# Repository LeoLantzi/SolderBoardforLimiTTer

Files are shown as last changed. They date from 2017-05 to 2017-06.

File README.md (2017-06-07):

# SolderBoardforLimiTTer
Ideas to solder LimiTTer componets on a pcb board instead of wiring, to make it simpler and save space.

worked for me, but put the charger bit outside not like intended.
The +3.3V pin  for the Sparkfun  usb lipo charger needs extra care in insulating to the arduino BLK pin, or scrap it off of and use an wire.
If I ever make an revision: As the first BM019pin is not used, cut it off. And make a small cutout on the board  and place usb port of the lipo charge .

made +20 if anybody wants them, message me

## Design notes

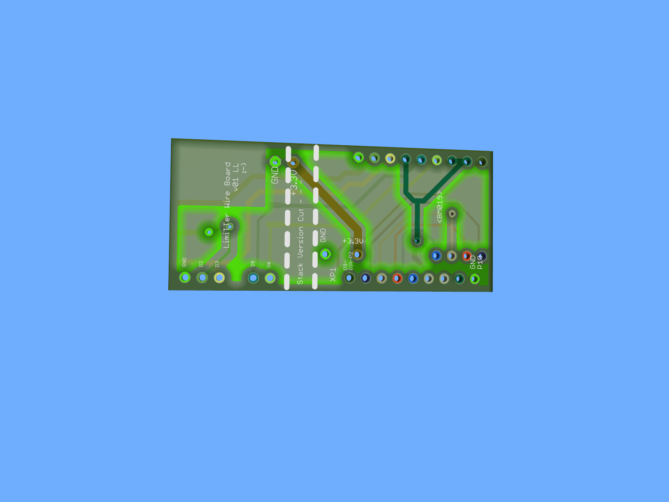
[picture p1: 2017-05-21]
ScreenShot_(1).png

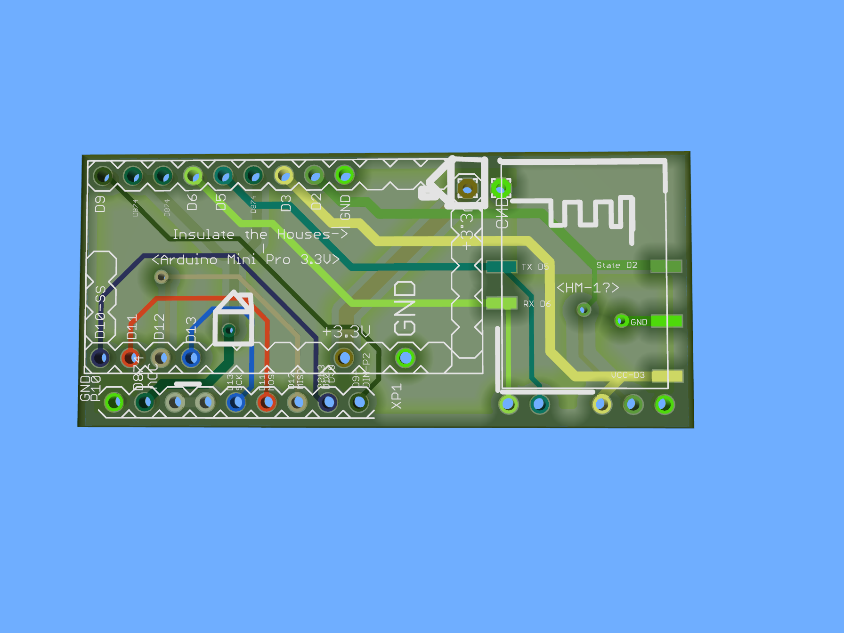
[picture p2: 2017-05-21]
ScreenShot_.png

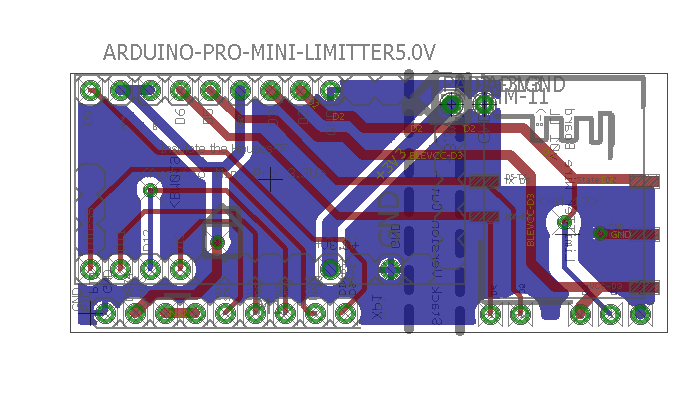
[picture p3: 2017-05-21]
image_wires.png

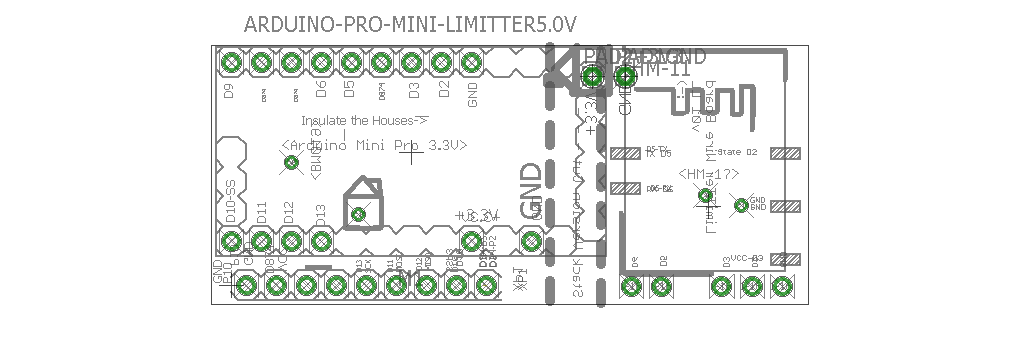
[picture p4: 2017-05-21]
image_one.png

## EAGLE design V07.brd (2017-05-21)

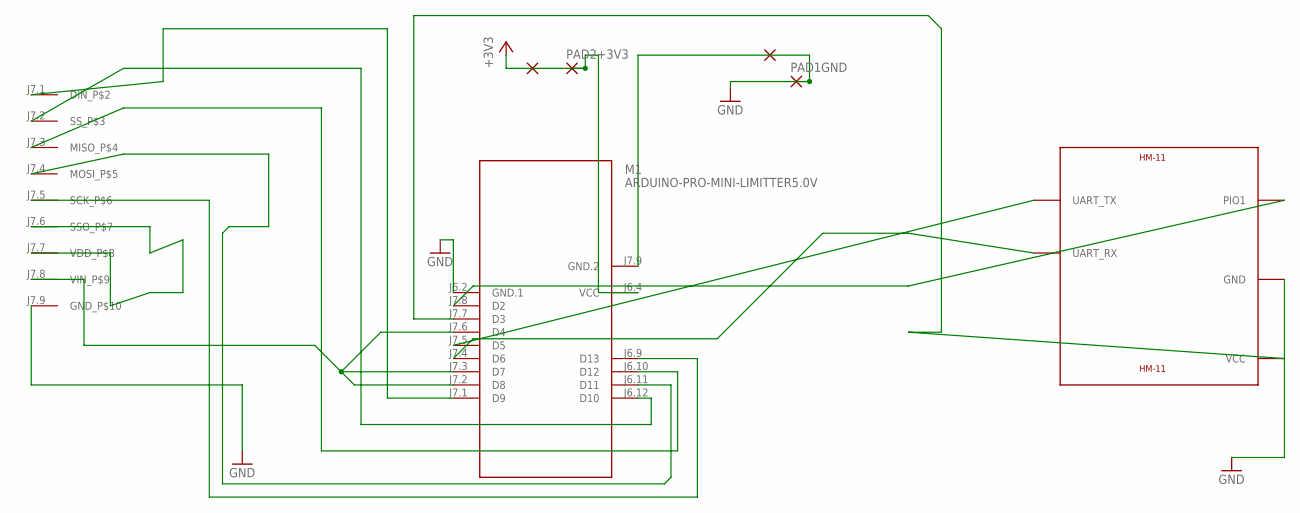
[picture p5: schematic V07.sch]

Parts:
M1: ARDUINO-PRO-MINI-LIMITTER5.0V; ARDUINO-PRO-MINI
PAD1GND, PAD2+3V3: 1,6/0,8
U$1: ARDUINO-9PIN1MM
U$2: HM-11

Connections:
+3V3: M1.J6.4 (VCC), PAD2+3V3.1
BLEVCC-D3: M1.J7.7 (D3), U$2.VCC
D2: M1.J7.8 (D2), U$2.PIO1
D5: M1.J7.5 (D5), U$2.UART_TX
D6: M1.J7.4 (D6), U$2.UART_RX
D10: M1.J6.12 (D10), U$1.J7.2 (SS_P$3)
D11: M1.J6.11 (D11), U$1.J7.4 (MOSI_P$5)
D12: M1.J6.10 (D12), U$1.J7.3 (MISO_P$4)
D13: M1.J6.9 (D13), U$1.J7.5 (SCK_P$6)
DINP2: M1.J7.1 (D9), U$1.J7.1 (DIN_P$2)
GND: M1.J6.2 (GND.1), M1.J7.9 (GND.2), PAD1GND.1, U$1.J7.9 (GND_P$10), U$2.GND
unnamed: U$1.J7.6 (SSO_P$7), U$1.J7.7 (VDD_P$8)
VINP9-D8D7D4: M1.J7.2 (D8), M1.J7.3 (D7), M1.J7.6 (D4), U$1.J7.8 (VIN_P$9)

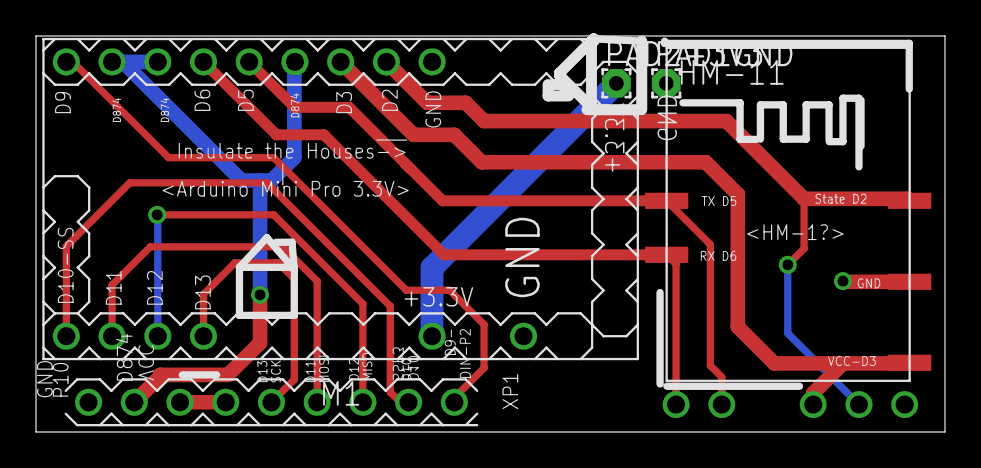
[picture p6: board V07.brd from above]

Board: 2 copper layers, 50.5 x 22.0 mm, 5 parts (0 on the bottom side), 13 nets.

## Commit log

2017-05-21 long version and possible to cut to stack for higher
    currently waiting on the 0.8mm boards.
    [V07.brd, V07.sch]
2017-05-21 Front mount Arduinio + hm1x
2017-05-21 Back mount BM019 and Sparkfun Charger
